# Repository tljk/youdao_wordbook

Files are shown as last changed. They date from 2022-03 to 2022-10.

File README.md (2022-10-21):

# 有道单词卡
基于微雪2.13墨水屏模块开发，实现单词学习/复习，词库同步有道单词本  
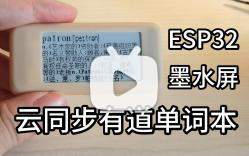
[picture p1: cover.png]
(https://www.bilibili.com/video/BV1yv4y1M7Wo)
  

## 前言
单词本里加了很多的单词，但是不见得就去复习  
所以就有了一个idea，一个随身携带可以同步的墨水屏单词本设备，结合墨水屏特性(低功耗，持久显示)利用碎片时间复习  
市面上已经出现了类似的产品，也更便宜更成熟，但是有道的一套用的很久了，并不想转到新的平台，于是乎就有了这个尝试  
  
目前的定位是能同步有道个人单词本的单词复习工具  
## 已经实现
联网爬取有道账号下单词本列表  
btree保存  
根据随机数遍历随机次实现随机单词  
显示单词释义，排版切换字体  
异步执行按键监听和爬虫  
休眠唤醒  
使用有道桌面版或者web版可以更新内容
音标显示

## 将要实现
复习模式，记录单词复习情况（记得/不记得），根据记录选择复习的单词    
联网释义    
状态显示  
同步删除  

## 使用模块
  
https://www.waveshare.net/shop/2.13inch-e-Paper-Cloud-Module.htm

## 安装
1. 下载  
   本仓库  
   模块驱动并安装
2. 连接模块，在设备管理器中显示  
3. 刷入镜像  
   python环境，安装工具包  
   `pip install esptool`  
   清除flash，COM4对应着设备端口号  
   `esptool.py --port COM4 erase_flash`  
   刷入对应镜像  
   `esptool.py --chip esp32 --port COM4 write_flash -z 0x1000 esp32_1.17_fb_boost_4M_ULAB.bin`  
   新增1.19.1，执行效率高，预留空间更大   
4. 修改配置  
   切换到Spider_JS_ReverseParsin  
   `cd Spider_JS_ReverseParsin`  
   安装依赖  
   `pip install -r requirements.txt`  
   获取有道cookie  
   `python js逆向有道登录1.py`  
   成功后会打印账号对应cookie以及生成单词数据文件youdao.json  
   将cookie填入wbconfig.py中"cookie="后  
   修改wifi ssid和密码  
5. 预编译  
   `pip install mpy-cross==1.18`  
   执行build.bat  
   或者使用mpy-cross对boot.py除外的所有py文件执行编译  
     
   如果报错mpy-cross版本不兼容，需要重新安装对应版本重新编译  
   v5对应1.18及以下  
   v6对应1.19及以上  
   
6. 上传代码  
   安装vscode 安装Pymakr插件  
   使用vscode打开/build文件夹(编译后)  
   连接并upload代码  
     
   参考[在vscode里基于Pymakr插件进行esp32的micropython开发](https://www.bilibili.com/read/cv7262936)  

## 外壳
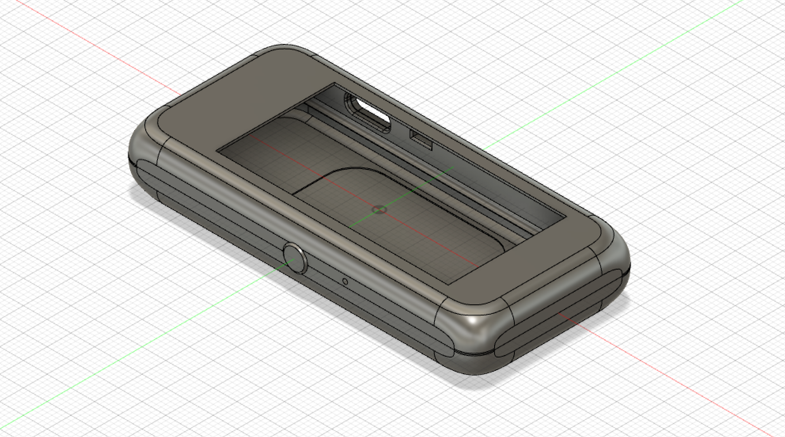
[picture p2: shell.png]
  
模型文件：[shell2 v8.f3d](https://github.com/tljk/youdao_wordbook/blob/master/shell2_v8.f3d), [shell2 v8.stl](https://github.com/tljk/youdao_wordbook/blob/master/shell2_v8.stl)  
壁面很薄，打印请使用刚性树脂，周围添加支撑

## 已知问题
1. OSError 28，空间不足或者data文件损坏
## 鸣谢
[framebuf中文](https://github.com/wangshujun-tj/mpy-Framebuf-boost-code)  
[cookie支持](https://github.com/mardigras2020/urequests)  
[epaper驱动](https://github.com/tljk/2.13inch-e-Paper-Cloud-Module-micropython-driver)  
[有道登录](https://github.com/WYL-BruceLong/Spider_JS_ReverseParsin)

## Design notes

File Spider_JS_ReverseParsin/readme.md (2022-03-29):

[toc]

## js逆向解析之有道登录

> js 逆向
1. 寻找关键点 -> 网络请求的一霎那
2. 对网络请求之前的代码进行分析
3. 比较难的js代码可以利用 js2py 让他去执行

### 项目需求分析
> 
实现有道登录以下是登录网址：
http://account.youdao.com/login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

### 爬虫的分析思路
- url
   ` https://logindict.youdao.com/login/acc/login`

- 请求方式
    `POST`

- 请求参数
    ```python
    'app': 'web',
    'tp': 'urstoken',
    'cf': 3,
    'fr': 1,
    'product': 'DICT',
    'type': 1,
    'um': 'true',
    'username': username,
    'password': context.aaa,
    'ru': 'http://dict.youdao.com/search?q=as&tab=#keyfrom=${keyfrom}'
    ```
    
- 请求头
	` 'User-Agent': 'Mozilla/5.0 (Windows NT 10.0; Win64; x64) AppleWebKit/537.36 (KHTML, like Gecko) Chrome/67.0.3396.99 Safari/537.36'`
    
### 详细分析（图文版）
#### 第一步：把网址copy到浏览器，进入后按f12进入控制台



#### 第二步：故意输入一个错误的密码查看控制台的变化并找到post请求的网页接口分析



- 登录接口和请求方式



- 请求参数



### 找到js入口，分析加密方式
####  方法一
- 回退一下到登录页面，找到form里有用的参数这里以`validate`为关键字参数


- 运用google浏览器实现搜索



- 找到对应的函数，并对js进行优化输出



- 找到加密的方法，并打上断点进行调试



- 找出`hex_md5`对应的js文件，保存下来





- 方法二
- 直接用加密的参数名也就是`请求参数`里的`password`进行全局搜索和方法一的前三步相同
- 这样也能找到相应的参数总共有13个password这里是第`12个位置`的password


### 完整的实现代码
```python

# 导入使用的模块
import js2py
import requests

# 请求的url接口地址
url = 'https://logindict.youdao.com/login/acc/login'

# 利用js2py构造一个上下文中间变量
context = js2py.EvalJs()

# 需要登录的用户名和密码
username = 'username@163.com'
password = 'pasword'

# 需要执行加密的已下载的js文件
with open('logincom.js', 'r') as f:
    context.execute(f.read())

# 把密码放在js中间变量
context.password = password

# 需要执行的js代码，这里我自己改了，感觉没有必要用那么多参数，里面的aaa我任意定义的
js_string = '''
var aaa = hex_md5(password);
'''
# print(js_string)

context.execute(js_string)
# 打印测试加密后的密码数据
print(context.aaa)

# 请求参数（把构造后的完整的请求参数放到data字典中去）
data = {
    'app': 'web',
    'tp': 'urstoken',
    'cf': 3,
    'fr': 1,
    'product': 'DICT',
    'type': 1,
    'um': 'true',
    'username': username,
    'password': context.aaa,
    'ru': 'http://dict.youdao.com/search?q=as&tab=#keyfrom=${keyfrom}'
}

# 设置请求头，模拟浏览器
headers = {
    'User-Agent': 'Mozilla/5.0 (Windows NT 10.0; Win64; x64) AppleWebKit/537.36 (KHTML, like Gecko) Chrome/67.0.3396.99 Safari/537.36'
}

response = requests.post(url, headers=headers, data=data)

# 把解析后的数据保存在youdao.html
with open('youdao.html', 'wb') as f:
    f.write(response.content)

```

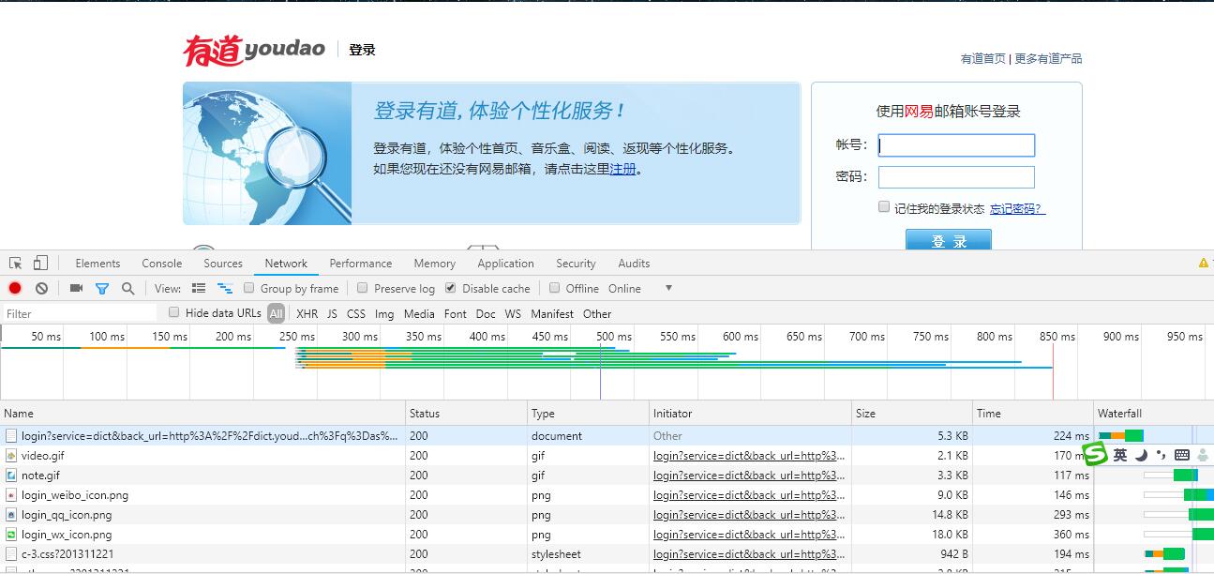
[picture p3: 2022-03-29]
Spider_JS_ReverseParsin/images/QQ截图20181111224331.jpg

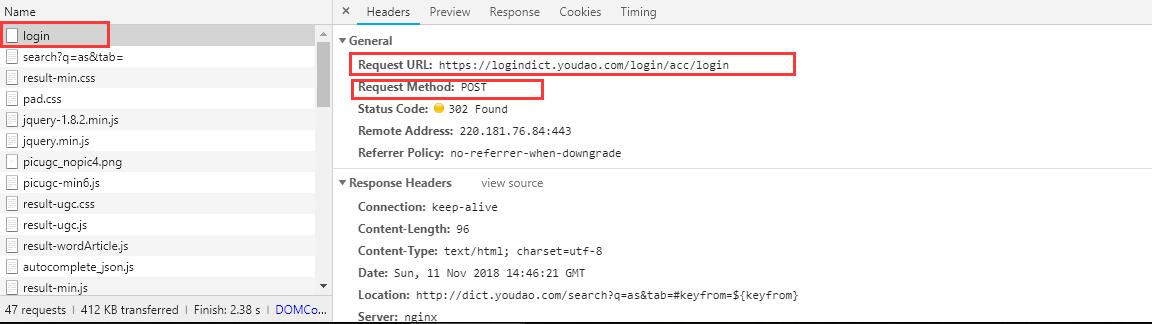
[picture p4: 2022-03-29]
Spider_JS_ReverseParsin/images/QQ截图20181111224951.jpg

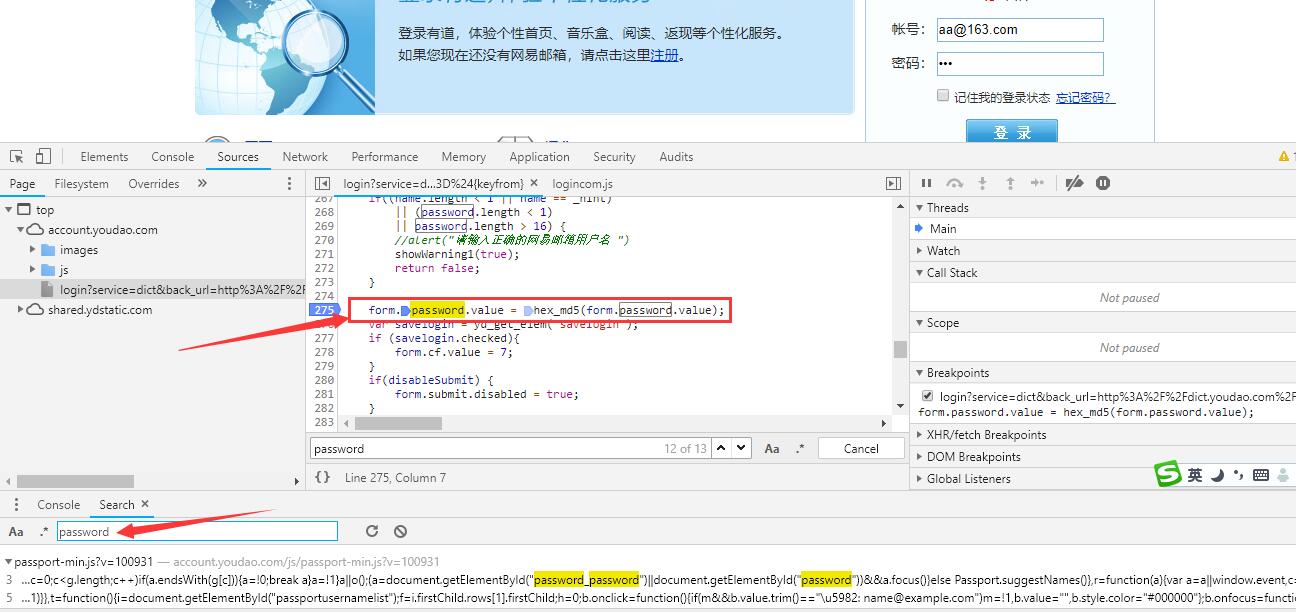
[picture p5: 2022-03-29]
Spider_JS_ReverseParsin/images/QQ截图20181111231620.jpg

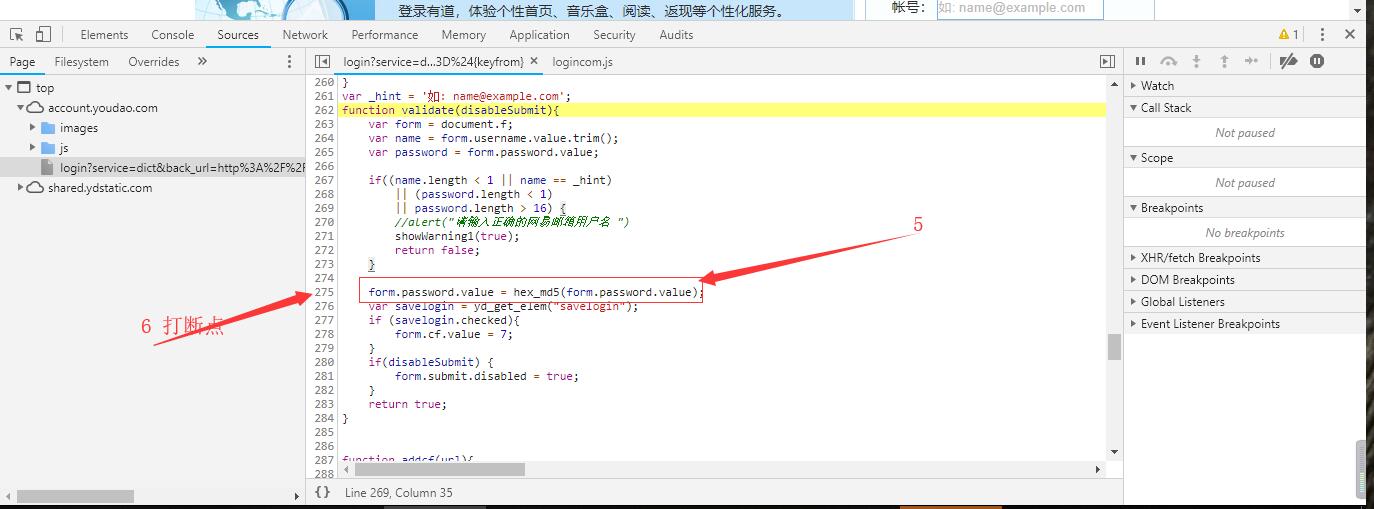
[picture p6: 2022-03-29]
Spider_JS_ReverseParsin/images/QQ截图20181111230101.jpg

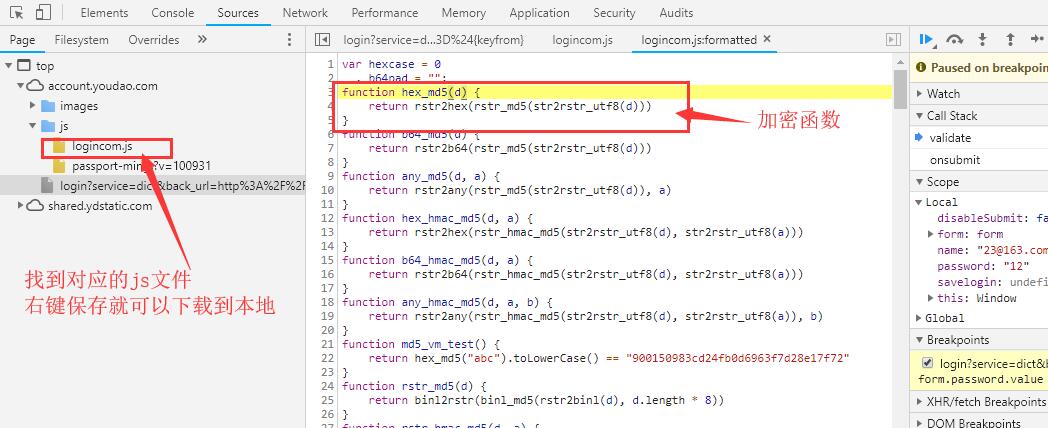
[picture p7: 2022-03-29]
Spider_JS_ReverseParsin/images/QQ截图20181111231149.jpg

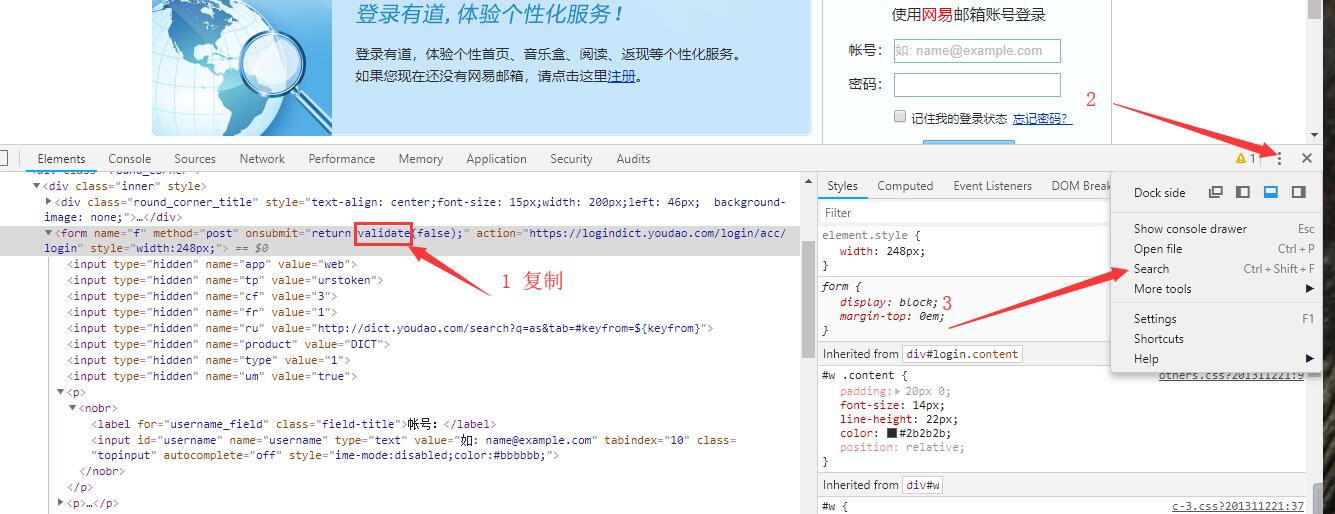
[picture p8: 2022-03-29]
Spider_JS_ReverseParsin/images/QQ截图20181111225833.jpg

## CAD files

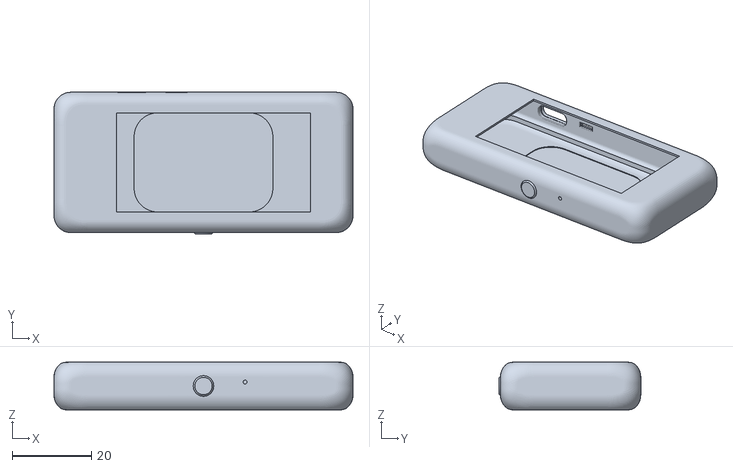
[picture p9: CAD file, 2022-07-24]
shell2_v8.stl
75.4 x 35.7 x 12.0

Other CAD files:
shell2_v8.f3d

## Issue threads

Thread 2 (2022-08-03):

似乎内存不足&有模块导入失败，原因未知

BlitherBoom812, 2022-08-03:
Traceback (most recent call last):
  File "boot.py", line 1, in <module>
  File "main.py", line 21, in <module>
MemoryError: memory allocation failed, allocating 1707 bytes
Traceback (most recent call last):
  File "main.py", line 21, in <module>
ImportError: can't import name EPD_2in13_V3
MicroPython v1.17 on 2021-09-22; ESP32 module with ESP32
Type "help()" for more information.

tljk, 2022-08-03:
- 至少4m内存
- 尝试重启
- 使用mpy-cross编译除boot.py外的所以py文件，win请直接使用build.bat一键编译

BlitherBoom812, 2022-08-04:
> * 至少4m内存
> * 尝试重启
> * 使用mpy-cross编译除boot.py外的所以py文件，win请直接使用build.bat一键编译

解决了，感谢！发现mpy-cross的版本必须是1.17，才能编译出mpy v5，和板子上的micropython版本适配，如果用最新版1.19编译出mpy v6就会不兼容。

INPEIU, 2022-10-07:
我的问题与你一样，但是怎么更换mpy-cross的版本？

Closed 2022-09-17.

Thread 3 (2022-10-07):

我的问题与“似乎内存不足&有模块导入失败，原因未知”应该是一样的，但是怎么更换mpy-cross的版本？

INPEIU, 2022-10-07:
Traceback (most recent call last):
  File "boot.py", line 1, in <module>
  File "main.py", line 19, in <module>
MemoryError: memory allocation failed, allocating 656 bytes
Traceback (most recent call last):
  File "main.py", line 19, in <module>
ImportError: can't import name EPD_2in13_V3
MicroPython v1.17 on 2021-09-22; ESP32 module with ESP32
Type "help()" for more information.

我的问题与“似乎内存不足&有模块导入失败，原因未知”   https://github.com/tljk/youdao_wordbook/issues/2
应该是一样的，但是怎么更换mpy-cross的版本？
我已经下载了micropython1.17的发行版压缩包
win11系统，64位，
板子是在仓库内的链接购买的

tljk, 2022-10-08:
`pip install mpy-cross==1.18`
or manually
[https://gitlab.com/alelec/mpy_cross/-/pipelines?scope=tags&page=1(url)

INPEIU, 2022-10-08:
好吧，现在是这个
Traceback (most recent call last):
  File "boot.py", line 1, in <module>
  File "F:\ϵͳĬ��\����\youdao_wordbook-master\src\main.py", line 18, in <module>
ImportError: no module named 'urequests'
MicroPython v1.17 on 2021-09-22; ESP32 module with ESP32
Type "help()" for more information.

INPEIU, 2022-10-08:
感谢！！！！！！！！！！成功啦！！！

Closed 2022-10-08.

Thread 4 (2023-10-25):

执行build报错

m986883511, 2023-10-25:
conda activate mpy
(mpy) PS Z:\code\tmp\esp32\youdao_wordbook> .\build.bat
找不到 Z:\code\tmp\esp32\youdao_wordbook\build\boot.py
已复制         1 个文件。
src\GB2312-24.fon
已复制         1 个文件。
子目录或文件 src 已经存在。
处理: src 时出错。
子目录或文件 build 已经存在。
处理: build 时出错。
(mpy) PS Z:\code\tmp\esp32\youdao_wordbook>

tljk, 2023-10-26:
这些报错可以忽略，请检查build文件夹下的内容。

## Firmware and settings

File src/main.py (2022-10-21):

# This file is executed on every boot (including wake-boot from deepsleep)
#import esp
#esp.osdebug(None)
#import webrepl
#webrepl.start()

import network
import ujson
import uasyncio
import random
import wbconfig
import machine
import gc
import os
import time
import esp32

from machine import Pin, RTC
from urequests import request
from epd import EPD_2in13_V3
from db import DB
class Wordbook:
    def __init__(self):
        self.epd = EPD_2in13_V3()
        self.db = DB()
        self.rtc = RTC()
        self.nvs = esp32.NVS('Wordbook')
        try:
            self.count = self.nvs.get_i32('curr') - 1
        except:
            self.count = random.randint(100,5000) # the count number traverse to next word
        self.epd.Clear()
        self.epd.fill(0xff)
        
        self.crawlerTSF = uasyncio.ThreadSafeFlag()
        self.epdTSF = uasyncio.ThreadSafeFlag()
        self.lock = uasyncio.Lock()
        self.epdTSF.set()
        self.crawlerTSF.set()

        self.startup = True # force crawler retry when startup

        self.tick = 0
        self.b1 = Pin(12, Pin.IN, Pin.PULL_UP)
        self.b1.irq(trigger=Pin.IRQ_FALLING, handler=lambda t:self.press())
        esp32.wake_on_ext0(pin = self.b1, level = esp32.WAKEUP_ALL_LOW)
        print('button init')
        
    # wifi
    async def crawler(self):
        while True:
            await self.crawlerTSF.wait() # critical point
            await self.lock.acquire()
            
            try:
                self.wifi = network.WLAN(network.STA_IF)
                self.wifi.active(True) 
                wifiList = self.wifi.scan()

                for w in wifiList:
                    w = w[0].decode('utf-8')
                    if w in wbconfig.wifi:
                        print('start to connect: '+w)
                        self.wifi.config(reconnects=2)
                        self.wifi.connect(w,wbconfig.wifi[w])
                        while not self.wifi.isconnected() and self.wifi.status() not in [15,203,200,204,205,201,202]:
                            await uasyncio.sleep(1)   # not in error status, wait
                            print(self.wifi.status())
                        if self.wifi.isconnected():
                            break
                
                if not self.wifi.isconnected():
                    print('wifi connect failed')
                else:
                    # time
                    import ntptime
                    ntptime.settime()
                    print(self.rtc.datetime())
                    print(os.statvfs('/'))

                    # cookie
                    res = request('GET','http://dict.youdao.com/wordbook/webapi/words', params=wbconfig.param, cookies=wbconfig.cookie)
                    await res.saveYoudao(self.db)

            except BaseException as e:
                import sys
                sys.print_exception(e)
                if self.startup:
                    self.crawlerTSF.set()
            else:
                self.startup = False

            self.db.flush()
            self.lock.release()
            self.wifi.active(False) 
            gc.collect()
    
    def press(self):
        now = time.ticks_ms()
        if time.ticks_diff(now, self.tick) > 300: # debouncing
            self.epdTSF.set()
        # print(self.tick, now)
        self.tick = now

    async def hiber(self):
        while True:
            await uasyncio.sleep(5)
            if not self.lock.locked():
                print('sleep')
                self.epd.sleep()
                await uasyncio.sleep(0.5)
                machine.lightsleep(1000*60*60)
                # print(machine.wake_reason())
                if machine.wake_reason() == 4:
                    self.crawlerTSF.set()
                else:
                    self.epd.reset()

    async def screen(self):
        print('screen init')

        while True:
            await uasyncio.sleep(0)
            index = 0
            try:
                for w in self.db.data.items():
                    index += 1

                    if self.count > 0:
                        self.count -= 1
                    else:
                        await self.epdTSF.wait() # critical point

                        machine.freq(240000000)
                        # print('load data')
                        gc.collect()
                        # print(gc.mem_free())
                        self.epd.frame(index, w[0], ujson.loads(w[1].decode('utf-8')))  
                        self.epd.display_Partial(self.epd.bufferTrans)

                        self.nvs.set_i32('curr',index)
                        self.nvs.commit()
                        self.count = 0
                        machine.freq(80000000)
                        
            except KeyboardInterrupt:
                break
            except BaseException as e:
                import sys
                sys.print_exception(e)

            # self.count = random.randint(100,5000)

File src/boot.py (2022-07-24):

from main import Wordbook
import uasyncio

def set_global_exception():
    def handle_exception(loop, context):
        import sys
        sys.print_exception(context["exception"])
        # sys.exit()
    loop = uasyncio.get_event_loop()
    loop.set_exception_handler(handle_exception)

async def main():
    set_global_exception()  # Debug aid
    wb = Wordbook()
    await uasyncio.gather(wb.crawler(),wb.screen(),wb.hiber(),return_exceptions=True)

    wb.epd.sleep()
    wb.epd.font_free()
    wb.db.close()
    wb.wifi.active(False) 

while True:
    try:
        uasyncio.run(main())
    finally:
        uasyncio.new_event_loop()  # Clear retained state

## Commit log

2022-04-01 fix bugs, update readme
    [boot.py]
2022-04-07 fix bug, exception after reopen db
    [boot.py]
2022-04-14 add 浅睡眠
2022-04-19 update readme, revise epaper driver
2022-05-30 fix 唤醒时间过长， 删去了按键多功能
2022-06-02 fix 空格消失，add 定时爬虫
2022-06-08 add 音标显示，内存优化
    [phonetic.xlsx]
2022-06-20 improve 逻辑优化，存储优化
2022-06-30 fix 排版出界，revise 爬虫逻辑
2022-07-24 fix oserror 28, add 更新单词, revise 排版优化, 逻辑优化
    [boot.py, main.py]
2022-08-09 add nvs还原单词进度
2022-08-10 improve 切换速度大幅提升，add epaper休眠
2022-08-16 revise 内存碎片优化
2022-10-21 add 1.19.1固件，update readme
